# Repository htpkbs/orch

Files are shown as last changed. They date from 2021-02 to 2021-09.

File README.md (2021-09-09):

# Overview

The orch is a keyboard PCB.

It has:

* A mostly ortholinear layout
* Key sizes that fit most GMK keycap sets
* 1.25u super/meta/command keys
* 19mm switch spacing
* An arrow key cluster
* A function key column
* USB-C
* A rotary encoder
* No stabilizers unless you want one for a 2U spacebar
* Optional 2U spacebar or 2 1U keys

# Key Layout

The key layout looks like this. (Thanks to [Keyboard Layout Editor](http://www.keyboard-layout-editor.com/) for the image.)

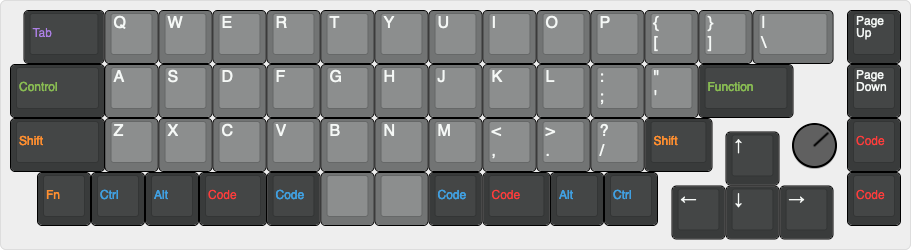
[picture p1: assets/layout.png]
Key layout


This is the corresponding data for pasting into Keyboard Layout Editor:

```
[{x:0.25,c:"#393b3b",t:"#9065c7",a:6,w:1.5},"Tab",{c:"#727474",t:"#c6c9c7",a:4,f:5},"Q","W","E","R","T","Y","U","I","O","P","{\n[","}\n]",{w:1.5},"|\n\\",{c:"#393b3b",x:0.25,t:"#c6c9c7",a:4,f:3},"Page\n\n\n\n\n\nUp"],
[{t:"#689b34",a:6,w:1.75},"Control",{c:"#727474",t:"#c6c9c7",a:4,f:5},"A","S","D","F","G","H","J","K","L",":\n;","\"\n'",{c:"#393b3b",t:"#689b34",a:6,f:3,w:1.75},"Function",{x:1,t:"#c6c9c7",a:4},"Page\n\n\n\n\n\nDown"],
[{t:"#ee6d00",a:6,w:1.75},"Shift",{c:"#727474",t:"#c6c9c7",a:4,f:5},"Z","X","C","V","B","N","M","<\n,",">\n.","?\n/",{c:"#393b3b",t:"#ee6d00",a:6,f:3,w:1.25},"Shift",{x:2.5,t:"#dd1126"},"Code"],
[{y:-0.75,x:13.25,t:"#c6c9c7",a:4,f:5},"&uarr;"],
[{y:-0.25,x:0.5,t:"#ee6d00",a:6,f:3},"Fn",{t:"#0084c2"},"Ctrl","Alt",{t:"#dd1126",w:1.25},"Code",{t:"#0084c2"},"Code",{c:"#727474",t:"#000000",a:7},"","",{c:"#393b3b",t:"#0084c2",a:6},"Code",{t:"#dd1126",w:1.25},"Code",{t:"#0084c2"},"Alt","Ctrl",{x:3.5,t:"#dd1126"},"Code"],
[{y:-0.75,x:12.25,t:"#c6c9c7",a:4,f:5},"&larr;","&darr;","&rarr;"]
```

# PCB Renders

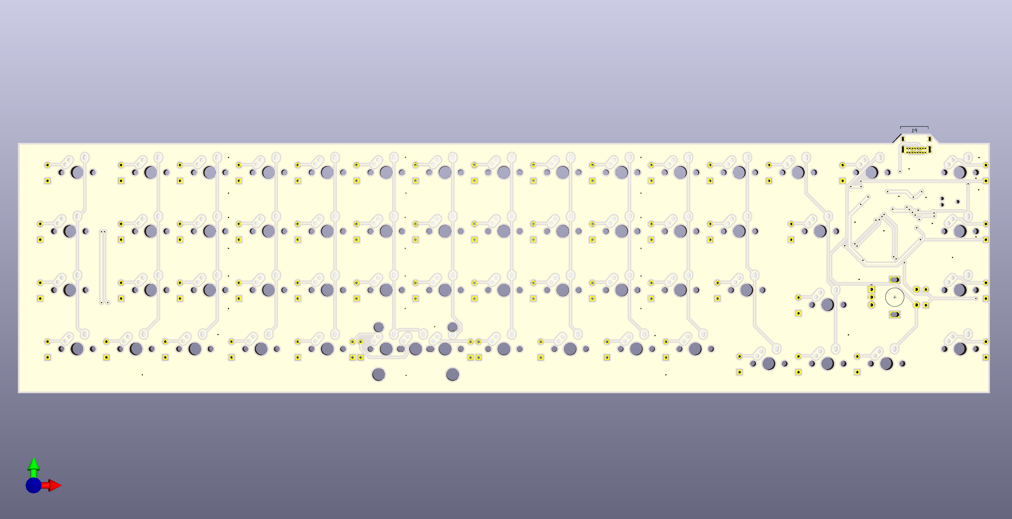
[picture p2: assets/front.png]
PCB front


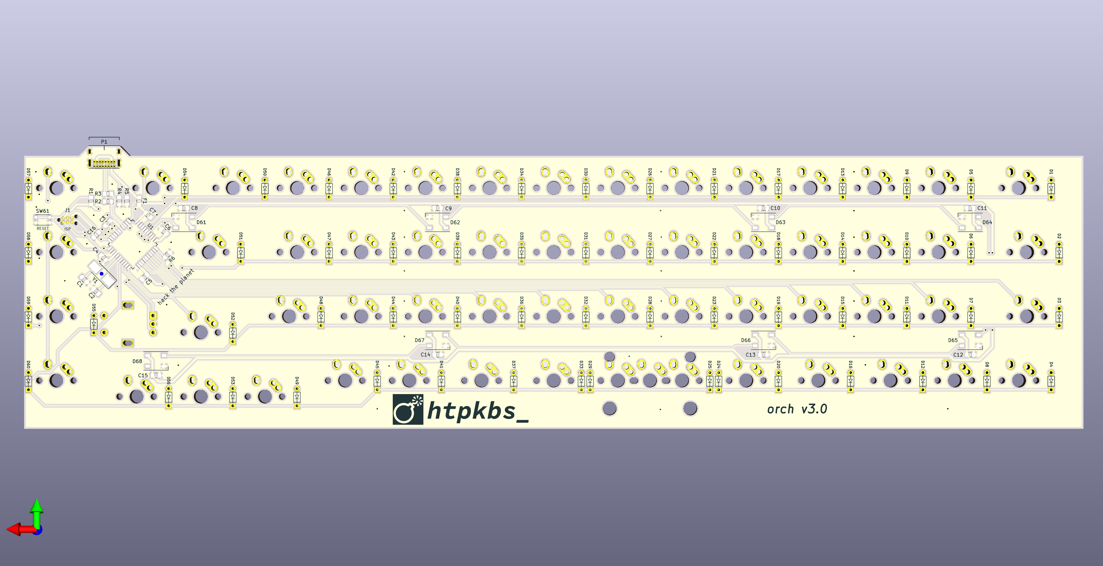
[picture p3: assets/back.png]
PCB back


# Case

[Case files are in the case directory](case) and include a cutout for the rotary encoder. The "closed" layer requires some dremeling or filing to make room for the USB connector. Thanks to the [swillkb Plate & Case Builder](http://builder.swillkb.com/). There are two bottom case files included. One of them has smaller holes that are meant for tapping (to secure the screws directly into the back case layer), and the other has "open" holes that an M2 screw will fit through (to secure the case together with nuts).

# Schematic

[There is a PDF of the schematic here](assets/schematic.pdf).

# AVR Notes

These are just some notes on programming the ATmega32U4. [The datasheet is here](http://ww1.microchip.com/downloads/en/DeviceDoc/Atmel-7766-8-bit-AVR-ATmega16U4-32U4_Datasheet.pdf).

## Programming

ISP headers are included in the "No Legs" Tag-Connect format. You need a Tag-Connect cable and retaining clip board to connect to it. For example, if you have an AVRISP mkII programmer, you need the ["No Legs" cable](https://www.tag-connect.com/product/tc2030-idc-nl) and the [retaining clip board](https://www.tag-connect.com/product/tc2030-retaining-clip-board-3-pack).

## Fuses

Default values are:

```
E:F3, H:99, L:5E
```

### Extended

| Name | Bit | Value | Status | Reason |
| --- | --- | --- | --- | --- |
| - | 7 | 1 | Unprogrammed | Unused |
| - | 6 | 1 | Unprogrammed | Unused |
| - | 5 | 1 | Unprogrammed | Unused |
| - | 4 | 1 | Unprogrammed | Unused |
| HWBE | 3 | 0 | Programmed | Pin used to force bootloader after reset |
| BODLEVEL2 | 2 | 0 | Programmed | 4.3V brown-out reset threshold |
| BODLEVEL1 | 1 | 0 | Programmed | 4.3V brown-out reset threshold |
| BODLEVEL0 | 0 | 0 | Programmed | 4.3V brown-out reset threshold |

Hex value is `F0`.

### High

| Name | Bit | Value | Status | Reason |
| --- | --- | --- | --- | --- |
| OCDEN | 7 | 1 | Unprogrammed | OCD disabled |
| JTAGEN | 6 | 0 | Programmed | JTAG enabled |
| SPIEN | 5 | 0 | Programmed | SPI enabled |
| WDTON | 4 | 1 | Unprogrammed | Watchdog timer in interrupt mode |
| EESAVE | 3 | 1 | Unprogrammed | EEPROM preserved on chip erase |
| BOOTSZ1 | 2 | 0 | Programmed | Default maximum boot size |
| BOOTSZ0 | 1 | 0 | Programmed | Default maximum boot size |
| BOOTRST | 0 | 1 | Unprogrammed | 4.3V brown-out reset threshold |

Hex value is `99`.

### Low

| Name | Bit | Value | Status | Reason |
| --- | --- | --- | --- | --- |
| CKDIV8 | 7 | 1 | Unprogrammed | Don't divide clock by 8 |
| CKOUT | 6 | 1 | Unprogrammed | Don't output clock |
| SUT1 | 5 | 0 | Programmed | Crystal oscillator with BOD enabled |
| SUT0 | 4 | 1 | Unprogrammed | Crystal oscillator with BOD enabled |
| CKSEL3 | 3 | 1 | Unprogrammed | Low power 16MHz crystal oscillator |
| CKSEL2 | 2 | 1 | Unprogrammed | Low power 16MHz crystal oscillator |
| CKSEL1 | 1 | 1 | Unprogrammed | Low power 16MHz crystal oscillator |
| CKSEL0 | 0 | 1 | Unprogrammed | Crystal oscillator with BOD enabled |

Hex value is `DD`.

### Setting Fuse Values

avrdude commands to set the fuse values with an AVRISP mkII programmer:

```
avrdude -p m32u4 -c avrispmkII -U efuse:w:0xF0:m
avrdude -p m32u4 -c avrispmkII -U hfuse:w:0x99:m
avrdude -p m32u4 -c avrispmkII -U lfuse:w:0xDD:m
```

Note that the extended fuse will always show as `C0` with avrdude (despite the datasheet saying that the first four bits are unprogrammed/`1111`).

You may need to erase the chip before you set the fuse values:

```
avrdude -p m32u4 -c avrispmkII -e
```

The first time flashing should be done with a programmer like the AVRISP mkII and you should compile QMK to include the bootloader in the firmware file (using `:production`). I have [a fork of the `qmk_firmware` repository here](https://github.com/htpkbs/qmk_firmware/tree/orch) that I may or may not try to get merged at some point.) To compile the `orch` branch with the QMK CLI:

```
qmk compile -kb orch -km default:production
```

I've had luck setting a custom bitclock setting (`-B`) for the initial flash when using the mkII, but this may not matter. For example:

```
avrdude -p m32u4 -c avrispmkII -U flash:w:orch_default_production.hex:i -B 154.37
```

You should now be able to flash regular (non-`:production`) firmware that doesn't include the bootloader over USB using QMK Tookbox.

# Sublicenses

* Thank you to [coseyfannitutti](https://github.com/coseyfannitutti) for the footprints `D_DO-35_SOD27_P5.08mm_Horizontal.kicad_mod` and `USB_C_GCT_USB4085.kicad_mod`. [The Creative Commons license for these is included here](LICENSE.CFTKB).
* Thanks to [ai03-2725](https://github.com/ai03-2725) for the `MX*` symbols. [The MIT license for these is included here](LICENSE.ai03).

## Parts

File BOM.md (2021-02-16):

# Bill of Materials

J1 (the Tag-Connect ISP headers) and SW1-SW60 (the key switches) are not included.

| Reference | Quantity | Value | Link |
| --- | --- | --- | --- |
| C1, C2 | 2 | 22pF | https://www.digikey.com/en/products/detail/avx-corporation/08055C220JAT2A/1602912 |
| C3 | 1 | 4.7u | https://www.digikey.com/en/products/detail/avx-corporation/08056D475KAT2A/563526 |
| C4-C13 | 4 | 0.1u | https://www.digikey.com/en/products/detail/avx-corporation/08053D104KAT2A/2345252 |
| C14 | 1 | 1u | https://www.digikey.com/en/products/detail/avx-corporation/0805DC105KAT2A/11245462 |
| D1-D60 | 60 | 1N4148 | https://www.digikey.com/product-detail/en/vishay-semiconductor-diodes-division/TZX3V6B-TR/TZX3V6B-TRGICT-ND/9601328 |
| D61-D66 | 6 | SK6812 | https://www.digikey.com/en/products/detail/adafruit-industries-llc/1655/5154679 |
| F1 | 1 | 100mA | https://www.digikey.com/en/products/detail/littelfuse-inc/0805L020YR/1212820 |
| P1 | 1 | USB_C_Receptacle_USB2.0 | https://www.digikey.com/product-detail/en/USB4085-GF-A/2073-USB4085-GF-ACT-ND/9859733 |
| R1, R6 | 2 | 10k | https://www.digikey.com/en/products/detail/bourns-inc/CR0805-FX-1002ELF/3593209 |
| R2, R3 | 2 | 22R | https://www.digikey.com/en/products/detail/bourns-inc/CR0805-FX-22R0ELF/3784764 |
| R4, R5 | 2 | 5.1k | https://www.digikey.com/en/products/detail/bourns-inc/CR0805-FX-5101ELF/3784995 |
| SW61 | 1 | Reset | https://www.digikey.com/en/products/detail/c-k/KMR241NG-LFS/2176486 |
| U1 | 1 | ATmega32U4-AU | https://www.digikey.com/en/products/detail/microchip-technology/ATMEGA32U4-AU/1914602 |
| Y1 | 1 | 16MHz | https://www.digikey.com/en/products/detail/abracon-llc/ABM3-16-000MHZ-B2-T/675298 |

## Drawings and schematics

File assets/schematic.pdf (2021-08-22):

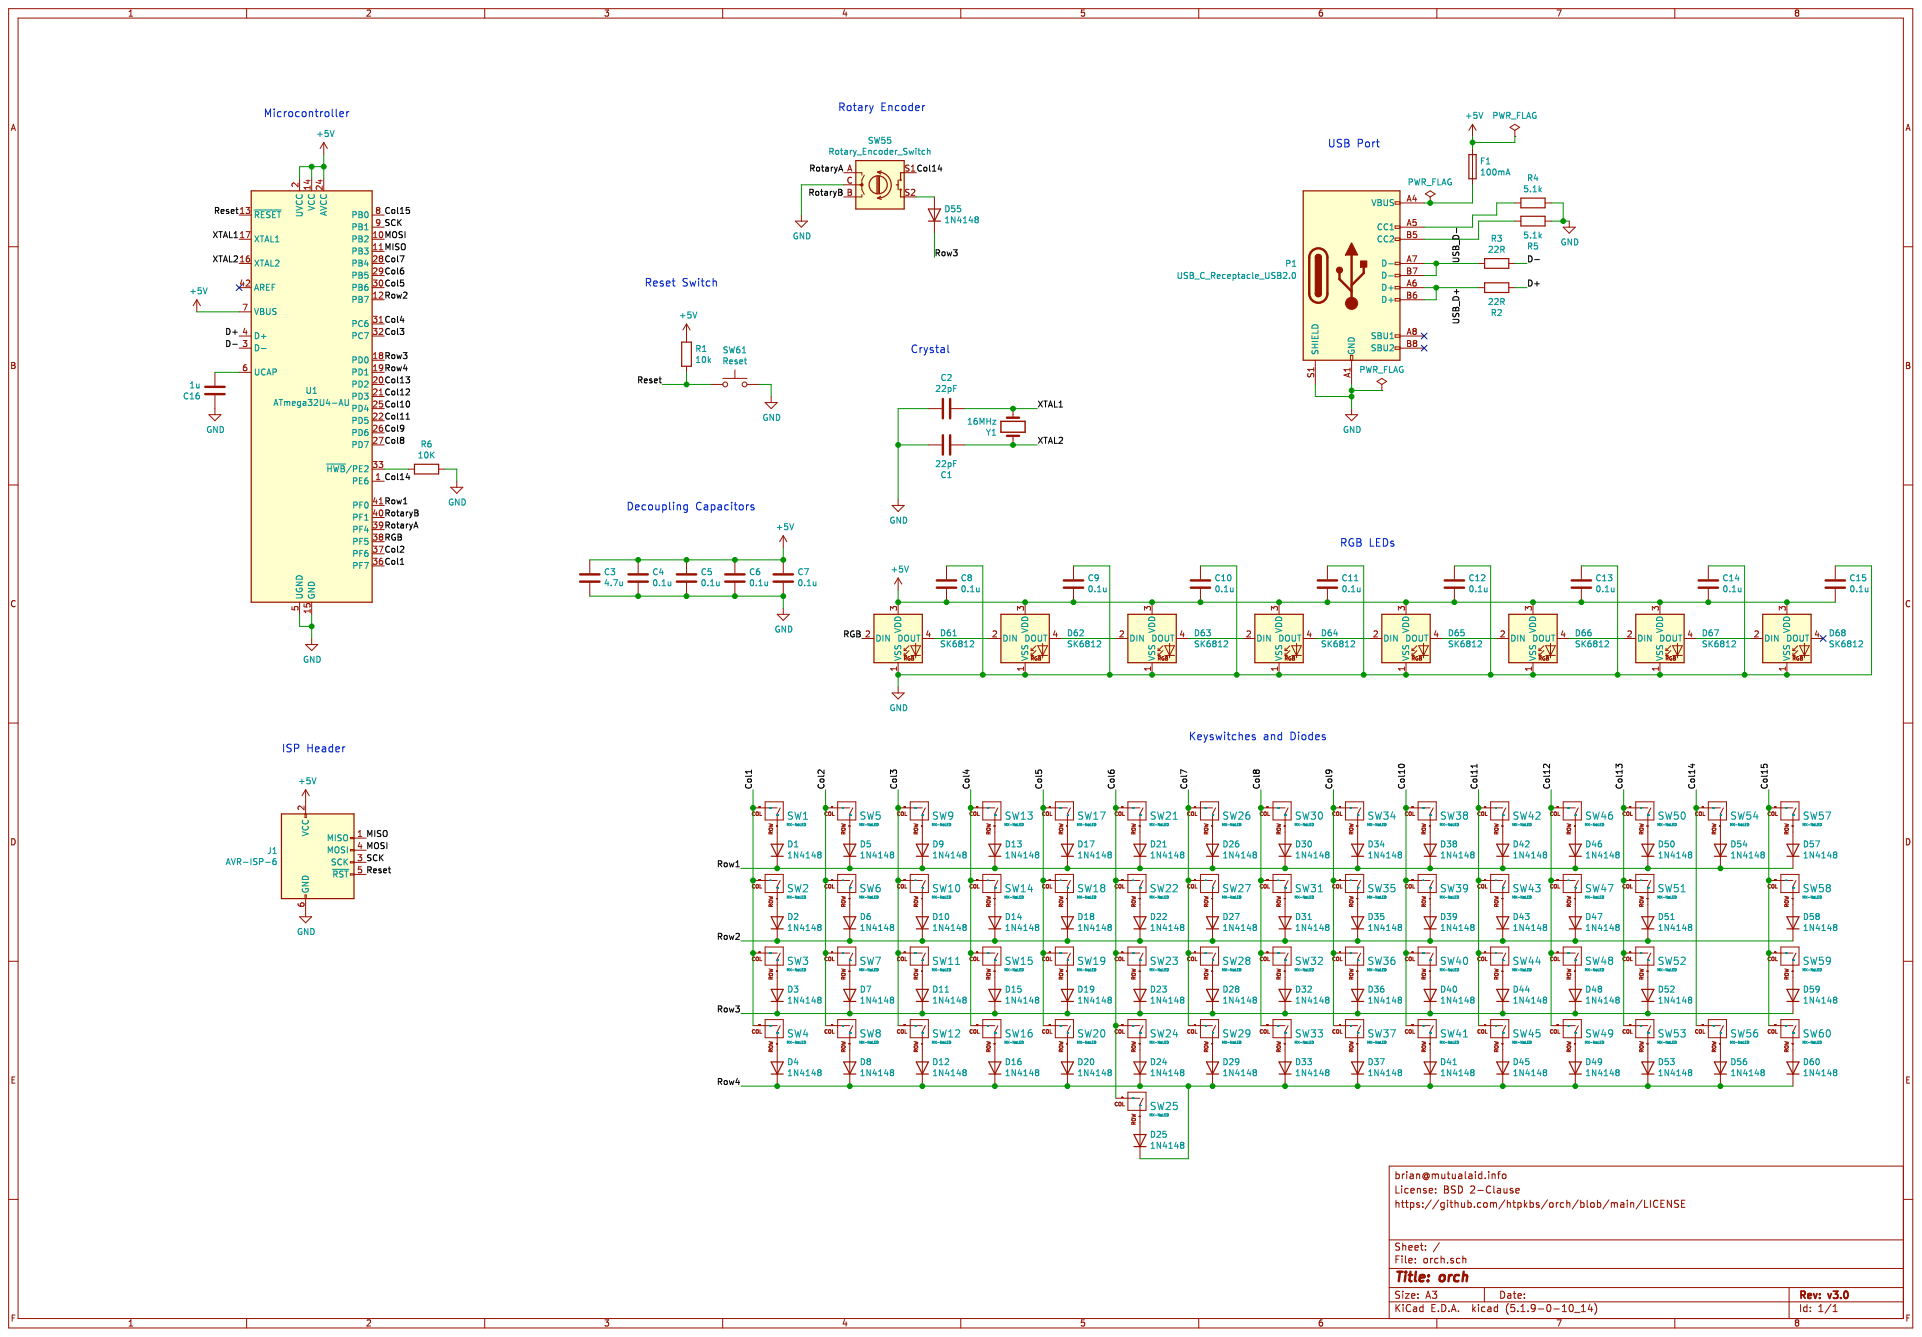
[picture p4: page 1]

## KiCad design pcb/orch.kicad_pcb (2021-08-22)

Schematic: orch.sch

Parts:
C1, C2: 22pF; C_0805_2012Metric_Pad1.18x1.45mm_HandSolder
C3: 4.7u; C_0805_2012Metric_Pad1.18x1.45mm_HandSolder
C4, C5, C6, C7, C8, C9, C10, C11, C12, C13, C14, C15: 0.1u; C_0805_2012Metric_Pad1.18x1.45mm_HandSolder
C16: 1u; C_0805_2012Metric_Pad1.18x1.45mm_HandSolder
D1, D2, D3, D4, D5, D6, D7, D8, D9, D10, D11, D12, D13, D14, D15, D16, D17, D18, D19, D20, D21, D22, D23, D24, D25, D26, D27, D28, D29, D30, D31, D32, D33, D34, D35, D36, D37, D38, D39, D40, D41, D42, D43, D44, D45, D46, D47, D48, D49, D50, D51, D52, D53, D54, D55, D56, D57, D58, D59, D60: 1N4148; D_DO-35_SOD27_P5.08mm_Horizontal
D61, D62, D63, D64, D65, D66, D67, D68: SK6812; LED_SK6812_PLCC4_5.0x5.0mm_P3.2mm
F1: 100mA; Fuse_0805_2012Metric_Pad1.15x1.40mm_HandSolder
J1: AVR-ISP-6; Tag-Connect_TC2030-IDC-NL_2x03_P1.27mm_Vertical
P1: USB_C_Receptacle_USB2.0; USB_C_GCT_USB4085
R1: 10k; R_0805_2012Metric_Pad1.15x1.40mm_HandSolder
R2, R3: 22R; R_0805_2012Metric_Pad1.15x1.40mm_HandSolder
R4, R5: 5.1k; R_0805_2012Metric_Pad1.15x1.40mm_HandSolder
R6: 10K; R_0805_2012Metric_Pad1.15x1.40mm_HandSolder
SW1, SW54: MX-NoLED; MX-1.5U-NoLED
SW2, SW3, SW51: MX-NoLED; MX-1.75U-NoLED
SW4, SW5, SW6, SW7, SW8, SW9, SW10, SW11, SW12, SW13, SW14, SW15, SW17, SW18, SW19, SW20, SW21, SW22, SW23, SW24, SW26, SW27, SW28, SW29, SW30, SW31, SW32, SW33, SW34, SW35, SW36, SW38, SW39, SW40, SW41, SW42, SW43, SW44, SW45, SW46, SW47, SW49, SW50, SW52, SW53, SW56, SW57, SW58, SW59, SW60: MX-NoLED; MX-1U-NoLED
SW16, SW37, SW48: MX-NoLED; MX-1.25U-NoLED
SW25: MX-NoLED; MX-2U-NoLED
SW55: Rotary_Encoder_Switch; RotaryEncoder_Alps_EC11E-Switch_Vertical_H20mm
SW61: Reset; SW_Push_1P1T_NO_CK_KMR2
U1: ATmega32U4-AU; TQFP-44_10x10mm_P0.8mm
Y1: 16MHz; Crystal_SMD_Abracon_ABM3-2Pin_5.0x3.2mm_HandSoldering

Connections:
+5V: C3.2, C4.2, C5.2, C6.2, C7.2, C8.1, C9.1, C10.1, C11.1, C12.1, C13.1, C14.1, C15.1, D61.3, D62.3, D63.3, D64.3, D65.3, D66.3, D67.3, D68.3, F1.1, J1.2, R1.1, U1.2, U1.7, U1.14, U1.24, U1.34, U1.44
/Col1: SW1.2, SW2.2, SW3.2, SW4.2, U1.36
/Col2: SW5.2, SW6.2, SW7.2, SW8.2, U1.37
/Col3: SW9.2, SW10.2, SW11.2, SW12.2, U1.32
/Col4: SW13.2, SW14.2, SW15.2, SW16.2, U1.31
/Col5: SW17.2, SW18.2, SW19.2, SW20.2, U1.30
/Col6: SW21.2, SW22.2, SW23.2, SW24.2, SW25.2, U1.29
/Col7: SW26.2, SW27.2, SW28.2, SW29.2, U1.28
/Col8: SW30.2, SW31.2, SW32.2, SW33.2, U1.27
/Col9: SW34.2, SW35.2, SW36.2, SW37.2, U1.26
/Col10: SW38.2, SW39.2, SW40.2, SW41.2, U1.25
/Col11: SW42.2, SW43.2, SW44.2, SW45.2, U1.22
/Col12: SW46.2, SW47.2, SW48.2, SW49.2, U1.21
/Col13: SW50.2, SW51.2, SW52.2, SW53.2, U1.20
/Col14: SW54.2, SW55.S1, SW56.2, U1.1
/Col15: SW57.2, SW58.2, SW59.2, SW60.2, U1.8
/D+: R2.1, U1.4
/D-: R3.1, U1.3
/MISO: J1.1, U1.11
/MOSI: J1.4, U1.10
/RGB: D61.2, U1.38
/Reset: J1.5, R1.2, SW61.1, U1.13
/RotaryA: SW55.A, U1.39
/RotaryB: SW55.B, U1.40
/Row1: D1.1, D5.1, D9.1, D13.1, D17.1, D21.1, D26.1, D30.1, D34.1, D38.1, D42.1, D46.1, D50.1, D54.1, D57.1, U1.41
/Row2: D2.1, D6.1, D10.1, D14.1, D18.1, D22.1, D27.1, D31.1, D35.1, D39.1, D43.1, D47.1, D51.1, D58.1, U1.12
/Row3: D3.1, D7.1, D11.1, D15.1, D19.1, D23.1, D28.1, D32.1, D36.1, D40.1, D44.1, D48.1, D52.1, D55.1, D59.1, U1.18
/Row4: D4.1, D8.1, D12.1, D16.1, D20.1, D24.1, D25.1, D29.1, D33.1, D37.1, D41.1, D45.1, D49.1, D53.1, D56.1, D60.1, U1.19
/SCK: J1.3, U1.9
/USB_D+: P1.A6 (D+), P1.B6 (D+), R2.2
/USB_D-: P1.A7 (D-), P1.B7 (D-), R3.2
/XTAL1: C2.2, U1.17, Y1.1
/XTAL2: C1.2, U1.16, Y1.2
GND: C1.1, C2.1, C3.1, C4.1, C5.1, C6.1, C7.1, C8.2, C9.2, C10.2, C11.2, C12.2, C13.2, C14.2, C15.2, C16.2, D61.1, D62.1, D63.1, D64.1, D65.1, D66.1, D67.1, D68.1, J1.6, P1.A1 (GND), P1.A12 (GND), P1.B1 (GND), P1.B12 (GND), P1.S1 (SHIELD), R4.1, R5.1, R6.1, SW55.C, SW61.2, U1.5, U1.15, U1.23, U1.35, U1.43
unnamed: C16.1, U1.6
unnamed: D1.2, SW1.1
unnamed: D2.2, SW2.1
unnamed: D3.2, SW3.1
unnamed: D4.2, SW4.1
unnamed: D5.2, SW5.1
unnamed: D6.2, SW6.1
unnamed: D7.2, SW7.1
unnamed: D8.2, SW8.1
unnamed: D9.2, SW9.1
unnamed: D10.2, SW10.1
unnamed: D11.2, SW11.1
unnamed: D12.2, SW12.1
unnamed: D13.2, SW13.1
unnamed: D14.2, SW14.1
unnamed: D15.2, SW15.1
unnamed: D16.2, SW16.1
unnamed: D17.2, SW17.1
unnamed: D18.2, SW18.1
unnamed: D19.2, SW19.1
unnamed: D20.2, SW20.1
unnamed: D21.2, SW21.1
unnamed: D22.2, SW22.1
unnamed: D23.2, SW23.1
unnamed: D24.2, SW24.1
unnamed: D25.2, SW25.1
unnamed: D26.2, SW26.1
unnamed: D27.2, SW27.1
unnamed: D28.2, SW28.1
unnamed: D29.2, SW29.1
unnamed: D30.2, SW30.1
unnamed: D31.2, SW31.1
unnamed: D32.2, SW32.1
unnamed: D33.2, SW33.1
unnamed: D34.2, SW34.1
unnamed: D35.2, SW35.1
unnamed: D36.2, SW36.1
unnamed: D37.2, SW37.1
unnamed: D38.2, SW38.1
unnamed: D39.2, SW39.1
unnamed: D40.2, SW40.1
unnamed: D41.2, SW41.1
unnamed: D42.2, SW42.1
unnamed: D43.2, SW43.1
unnamed: D44.2, SW44.1
unnamed: D45.2, SW45.1
unnamed: D46.2, SW46.1
unnamed: D47.2, SW47.1
unnamed: D48.2, SW48.1
unnamed: D49.2, SW49.1
unnamed: D50.2, SW50.1
unnamed: D51.2, SW51.1
unnamed: D52.2, SW52.1
unnamed: D53.2, SW53.1
unnamed: D54.2, SW54.1
unnamed: D55.2, SW55.S2
unnamed: D56.2, SW56.1
unnamed: D57.2, SW57.1
unnamed: D58.2, SW58.1
unnamed: D59.2, SW59.1
unnamed: D60.2, SW60.1
unnamed: D61.4, D62.2
unnamed: D62.4, D63.2
unnamed: D63.4, D64.2
unnamed: D64.4, D65.2
unnamed: D65.4, D66.2
unnamed: D66.4, D67.2
unnamed: D67.4, D68.2
unnamed: F1.2, P1.A4 (VBUS), P1.A9 (VBUS), P1.B4 (VBUS), P1.B9 (VBUS)
unnamed: P1.A5 (CC1), R4.2
unnamed: P1.B5 (CC2), R5.2
unnamed: R6.2, U1.33

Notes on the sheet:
USB Port
Reset Switch
Microcontroller
Decoupling Capacitors
Keyswitches and Diodes
ISP Header
Crystal
RGB LEDs
Rotary Encoder

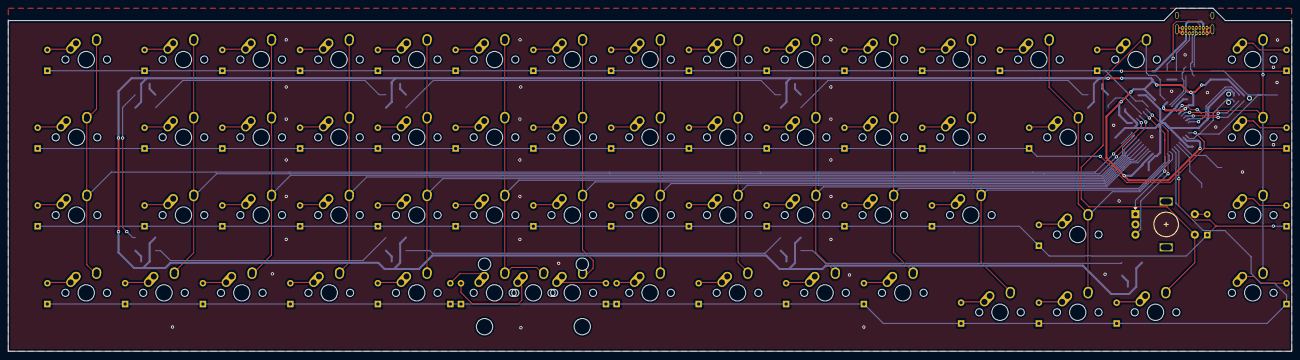
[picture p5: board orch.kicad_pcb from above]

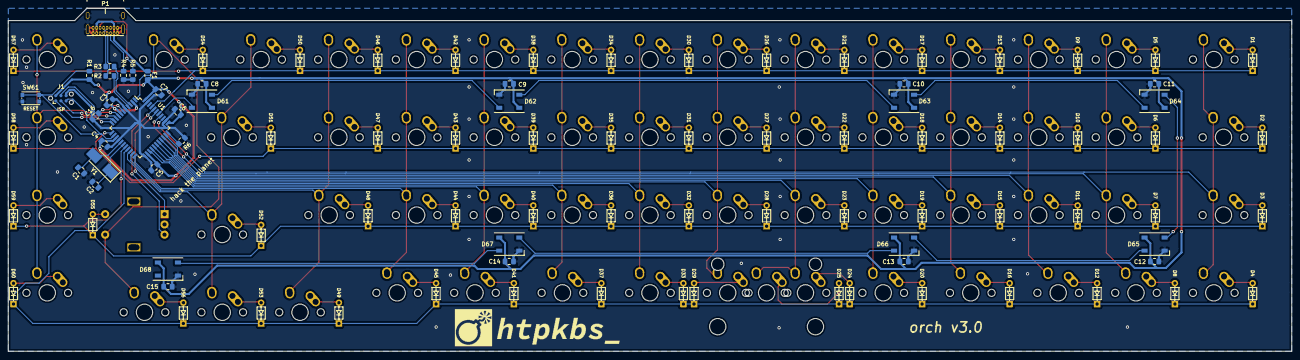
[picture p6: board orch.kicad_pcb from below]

Board: 2 copper layers, 313.6 x 83.8 mm, 156 parts (96 on the bottom side), 106 nets.

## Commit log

2021-01-15 pcb layout
    [orch.kicad_pcb, orch.sch]
2021-01-15 pcb done
    [orch.kicad_pcb, orch.sch]
2021-01-16 clean up pages
    [orch.kicad_pcb, orch.sch]
2021-01-19 new logos
    [orch.kicad_pcb]
2021-01-20 move logos
    [orch.kicad_pcb]
2021-01-26 add fuses
2021-01-28 fix rows and start new traces
    [orch.kicad_pcb, orch.sch]
2021-02-02 rotary encoder?
    [orch.sch]
2021-02-02 redo power
    [orch.kicad_pcb]
2021-02-08 add isp label
    [orch.kicad_pcb]
2021-02-08 add case files
2021-02-08 rotary encoder on layout
2021-02-08 some new case things, updated BOM
    [orch.sch]
2021-02-08 fix typo in bom
2021-02-12 fix caps for leds
    [orch.kicad_pcb, orch.sch]
2021-02-12 update schematic and renders
2021-02-16 v2.1 - add caps to LEDs, re-do some routing
    [orch.kicad_pcb, orch.sch]
2021-02-16 update bom, renumber caps
    [orch.sch]
2021-02-18 bump out usb connector
    [orch.kicad_pcb]
2021-02-23 some changes
    [orch.kicad_pcb]
2021-05-11 unused footprint
2021-08-21 flip usb
    [orch.kicad_pcb]
2021-09-06 Move case files around, update README

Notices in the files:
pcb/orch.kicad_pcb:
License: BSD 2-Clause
